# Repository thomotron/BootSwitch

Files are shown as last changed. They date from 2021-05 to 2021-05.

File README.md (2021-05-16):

# BootSwitch
A serial-fed operating system selector switch for GRUB built on the ATTiny85.

This will listen for a phrase being sent in over serial and send a series of keystrokes back if it picks up the correct phrase.

# Why?
I run both Linux and Windows simultaneously on my main PC using GRUB2 as my bootloader.
By default GRUB will boot into Linux, but I have to wait ~10s from powering on before GRUB will let me choose my OS.
I'd much rather flip a switch and walk away while it boots into my OS of choice, so here we are.

# Requirements
This is built to run on an ATTiny85 connected to an MSI Z97S Krait Edition motherboard through the JCOM1 header. It might work with other boards, YMMV.

You'll need:
- An ATTiny25/45/85
- A PC with a serial port
- A MAX232 (optional, for logic level conversion)
- An ISP that can flash an AVR (I used a USBtinyISP)
- `make`
- `avrdude`
- `avr-gcc` and `avr-libc`

# Building
Open the `Firmware` directory and run `make`.

There are a couple of make targets:  
`make fuse`: Burns the fuses into the AVR  
`make flash`: Flashes the firmware  
`make clean`: Cleans up build artifacts

Chip-specific settings (fuses, clock speed, ISP, etc.) are defined in the makefile and should be modified to suit your environment.

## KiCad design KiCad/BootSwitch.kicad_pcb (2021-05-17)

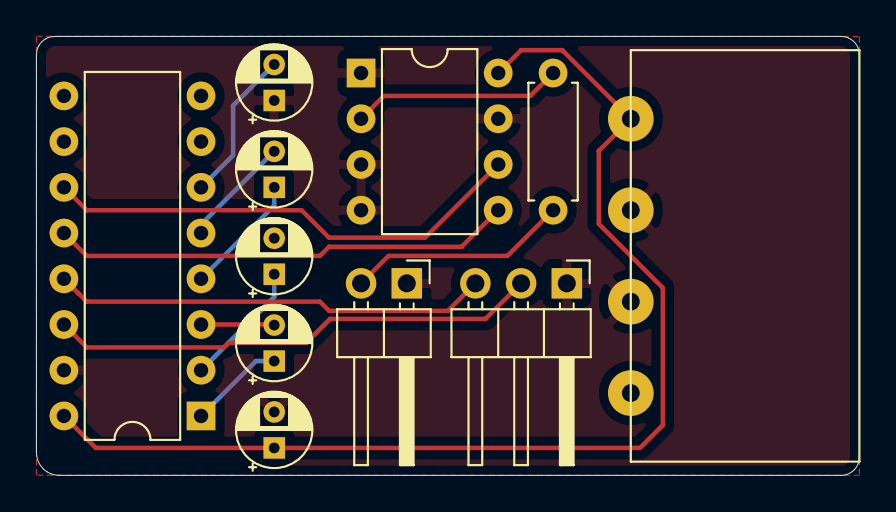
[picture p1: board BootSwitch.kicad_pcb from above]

Board: 2 copper layers, 45.7 x 24.4 mm, 11 parts (0 on the bottom side), 14 nets.

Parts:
C1, C2, C3, C4, C5: 1uF; CP_Radial_D4.0mm_P2.00mm
J1: JCOM1; PinHeader_1x03_P2.54mm_Horizontal
J2: Molex 8981-P04; MOLEX_8981_4P_Horizontal
R1: 10k; R_Axial_DIN0207_L6.3mm_D2.5mm_P7.62mm_Horizontal
SW1: Case Switch; PinHeader_1x02_P2.54mm_Horizontal
U1: ATtiny85-20PU; DIP-8_W7.62mm
U2: MAX232; DIP-16_W7.62mm

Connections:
5v: C1.1, J2.4, U1.8, U2.16
Earth: C1.2, C2.2, C5.1, J1.1, J2.2, J2.3, SW1.1, U1.1, U1.3, U1.4, U1.7, U2.15
unnamed: C2.1, U2.2
unnamed: C3.1, U2.1
unnamed: C3.2, U2.3
unnamed: C4.1, U2.4
unnamed: C4.2, U2.5
unnamed: C5.2, U2.6
unnamed: J1.2, U2.14
unnamed: J1.3, U2.13
unnamed: R1.1, SW1.2
unnamed: R1.2, U1.2
unnamed: U1.5, U2.12
unnamed: U1.6, U2.11

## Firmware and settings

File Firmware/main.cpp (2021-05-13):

#include <avr/io.h>
#include <util/delay.h>
#include <string.h>
#include <avr/interrupt.h>

#include "io_macros.h"

//#define DEBUG

#define TX_PIN B, 1
#define RX_PIN B, 0

#define SW_PIN B, 3

#define START LOW
#define STOP HIGH
#define BIT_WIDTH_US 104
#define BIT_WIDTH_HALF_US (BIT_WIDTH_US/2)

void init();
unsigned char recv_byte();
void send_byte(unsigned char byte);
bool compare_phrase();
inline bool uart_ready();
void handle_boot();
void data_append(char byte);
int main();

const unsigned char BOOT_PHRASE[] = "the ^ and v keys";
#define BOOT_PHRASE_LENGTH 16

// Ring buffer to store the incoming data
char data[BOOT_PHRASE_LENGTH];
int data_index = 0;

// Whether a byte has been received and is ready to be processed
volatile bool byte_received = false;

// The incoming byte
volatile unsigned char incoming_byte = 0;

// Pin change interrupt
ISR(PCINT0_vect)
{
    // Only handle the start bit
    if (!uart_ready()) return;

    // Synchronise to the middle of the bit and jump to the first data bit
    _delay_us(BIT_WIDTH_HALF_US);
    _delay_us(BIT_WIDTH_US);

    // Read in the byte
    incoming_byte = recv_byte();

    // Signal that a byte was received
    byte_received = true;
}

// Initialises the microcontroller
void init()
{
    cli();

    // Enable pullups
    MCUCR &= ~(1 << PUD);

    // Enable pin change interrupt for the RX pin
    GIMSK |= (1 << PCIE);
    PCMSK |= (1 << PCINT0);

    // Set pin directons
    PinMode(TX_PIN, OUTPUT);
    PinMode(RX_PIN, INPUT);
    PinMode(SW_PIN, INPUT);

    // Set initial pin states
    DigitalWrite(SW_PIN, HIGH); // Enable pullup
    DigitalWrite(TX_PIN, STOP);

    // Clear the data buffer
    memset(data, 0, BOOT_PHRASE_LENGTH);

    sei();
}

// Receives a byte from UART
unsigned char recv_byte()
{
    // Create a buffer to store the incoming byte in
    unsigned char recv_buf = 0;

    // Receive the next 8 bits
    for (unsigned char i = 0b00000001; i > 0; i <<= 1)
    {
        if (DigitalRead(RX_PIN)) recv_buf |= i;
        _delay_us(BIT_WIDTH_US);
    }

    // Wait for the stop bit to pass by
    //_delay_us(BIT_WIDTH_US);

    // Return the byte
    return recv_buf;
}

// Transmits a single byte over UART
void send_byte(unsigned char byte)
{
    // Send the start bit
    DigitalWrite(TX_PIN, START);
    _delay_us(BIT_WIDTH_US);

    // Send each bit LSB-first
    for (unsigned char i = 0b00000001; i > 0; i <<= 1)
    {
        DigitalWrite(TX_PIN, (byte & i));
        _delay_us(BIT_WIDTH_US);
    }

    // Send the stop bit
    DigitalWrite(TX_PIN, STOP);
    _delay_us(BIT_WIDTH_US);
}

// Compares the phrase to the ring buffer
bool compare_phrase()
{
    // Start at the data index, wrap around, and stop just before it
    int i = data_index;
    int j = 0;
    do
    {
        if (BOOT_PHRASE[j] != data[i]) return false;

        // Increment iterator and wrap around if necessary
        i++; j++;
        if (i == BOOT_PHRASE_LENGTH) i = 0;
    } while (i != data_index);

    return true;
}

// Checks whether the UART line is ready to send
inline bool uart_ready()
{
    return DigitalRead(RX_PIN) == START;
}

// Handle the boot response based on switch position
void handle_boot()
{
    // Disable interrupts while transmitting
    cli();

    if (DigitalRead(SW_PIN))
    {
        // Switch on, boot into Windows
        send_byte(0x76); // v
        send_byte(0x76); // v
        send_byte(0x76); // v
        send_byte(0x0D); // CR
    }
    else
    {
        // Switch off, boot into Linux
        send_byte(0x0D); // CR
    }

    // Re-enable interrupts
    sei();
}

// Appends a character to the data buffer
void data_append(char byte)
{
    // Data index is the current WRITE POSITION which will be overwritten on the next byte.
    // It is effectively at the head of the buffer, with the tail being one position behind it

    // Append the byte and advance the index
    data[data_index] = byte;
    data_index++;

    // Wrap around if necessary
    if (data_index == BOOT_PHRASE_LENGTH) data_index = 0;
}

int main()
{
    init();

    while (true)
    {
        // Wait until there is data available
        while (!byte_received);

        // Processing now, clear the flag
        byte_received = false;

        // Append the byte to the buffer
        data_append(incoming_byte);

        // Compare the ring buffer to the boot phrase
        if (compare_phrase())
        {
            // Make a boot selection
            handle_boot();
        }

#ifdef DEBUG
        // Print the current contents of the ring buffer
        for (int i = 0; i < BOOT_PHRASE_LENGTH; i++)
        {
            send_byte(data[i]);
        }
        send_byte('\r');
        send_byte('\n');
        // and a caret under the position of data_index
        for (int i = 0; i < data_index; i++)
        {
            send_byte(' ');
        }
        if (compare_phrase()) send_byte('!');
        else send_byte('^');
        send_byte('\r');
        send_byte('\n');
#endif
    }
}

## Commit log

2021-04-25 Initial commit 🎉
2021-04-26 Add schematic
    [BootSwitch.kicad_pcb, BootSwitch.sch]
2021-04-28 Fixed issues and got a working implementation
    Added debug section to view current buffer state
    Fixed send/receive shifting signed chars, causing send/receive to stop
    early
    Fixed buffer only using one iterator, therefore never matching unless
    the match was from the start of the buffer
    [main.cpp]
2021-05-08 Use Timer0 for rx bit timing
2021-05-10 Use pinterrupts to sync with the start bit
    Finally got a working implementation without absurd timing issues
    [main.cpp]
2021-05-13 Update schematic
    [BootSwitch.sch]
2021-05-17 Add KiCad schematic and xess parts lib
    [BootSwitch.kicad_pcb, BootSwitch.sch]
2021-05-17 Revise PCB for production
    [BootSwitch.kicad_pcb]
